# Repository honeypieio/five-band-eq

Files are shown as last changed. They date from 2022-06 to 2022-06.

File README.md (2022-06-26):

# Five-band EQ
Preamp and five-band EQ for guitar amplifiers

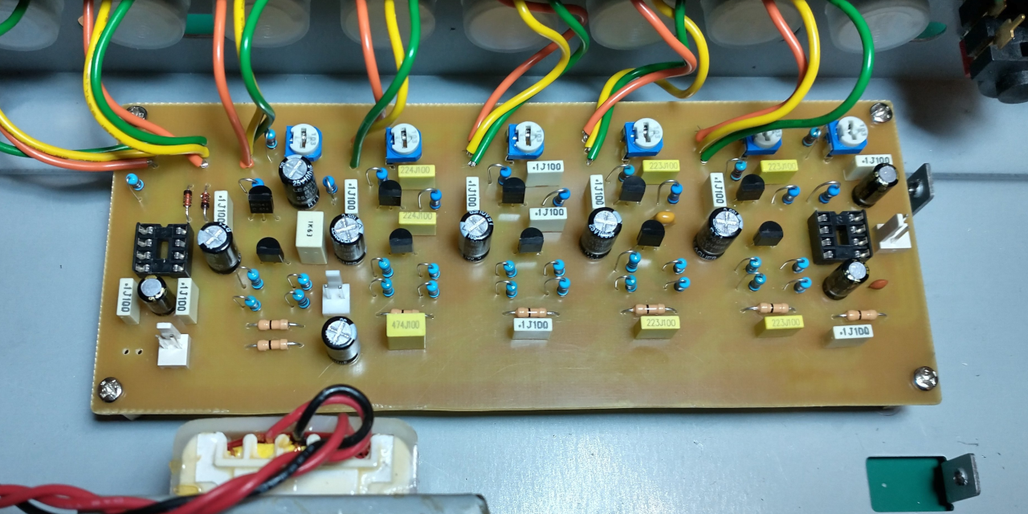
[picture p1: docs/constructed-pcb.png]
Photo of constructed PCB
 

The goal of this project is to create a simple guitar amplifier frontend using commonly available components

The PCB is single-sided and was created using Kicad. It is optimised for home etching - chunky traces, generous ground plane clearance

Key specifications:

* Requires a +/-15V power supply
* ~80mA quiescent current draw
* Adjustable input gain and attenuation
* Hard clipping diodes for distortion
* Five-band EQ - bass, middle, treble, presence, brilliance
* EQ 6dB boost/cut

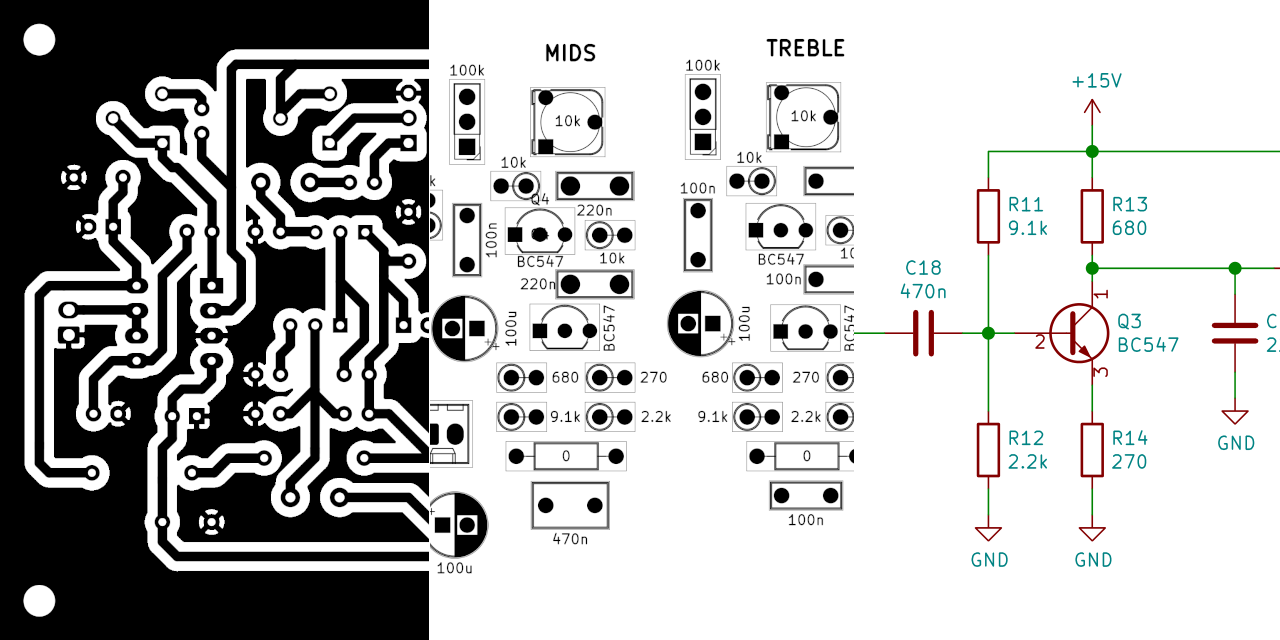
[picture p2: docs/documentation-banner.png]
Documentation banner
 

To build the project, everything needed is inside the `docs` directory

* PCB layout
* Bill of materials
* Silkscreen
* Schematics

An LTspice simulation is also available in the `simulation` directory

---

### To-do

* Add EQ alignment process instructions

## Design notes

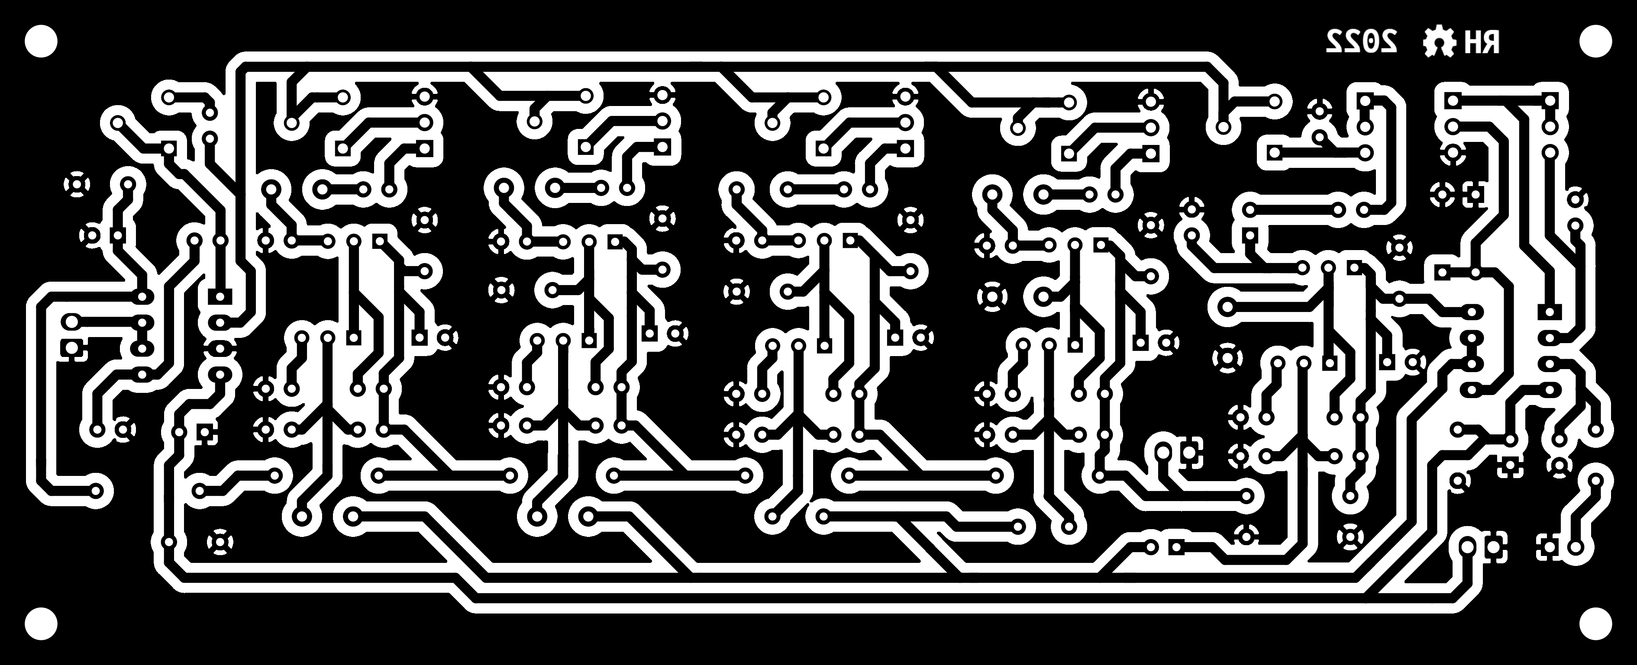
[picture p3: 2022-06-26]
docs/pcb-layout-copper-only.png

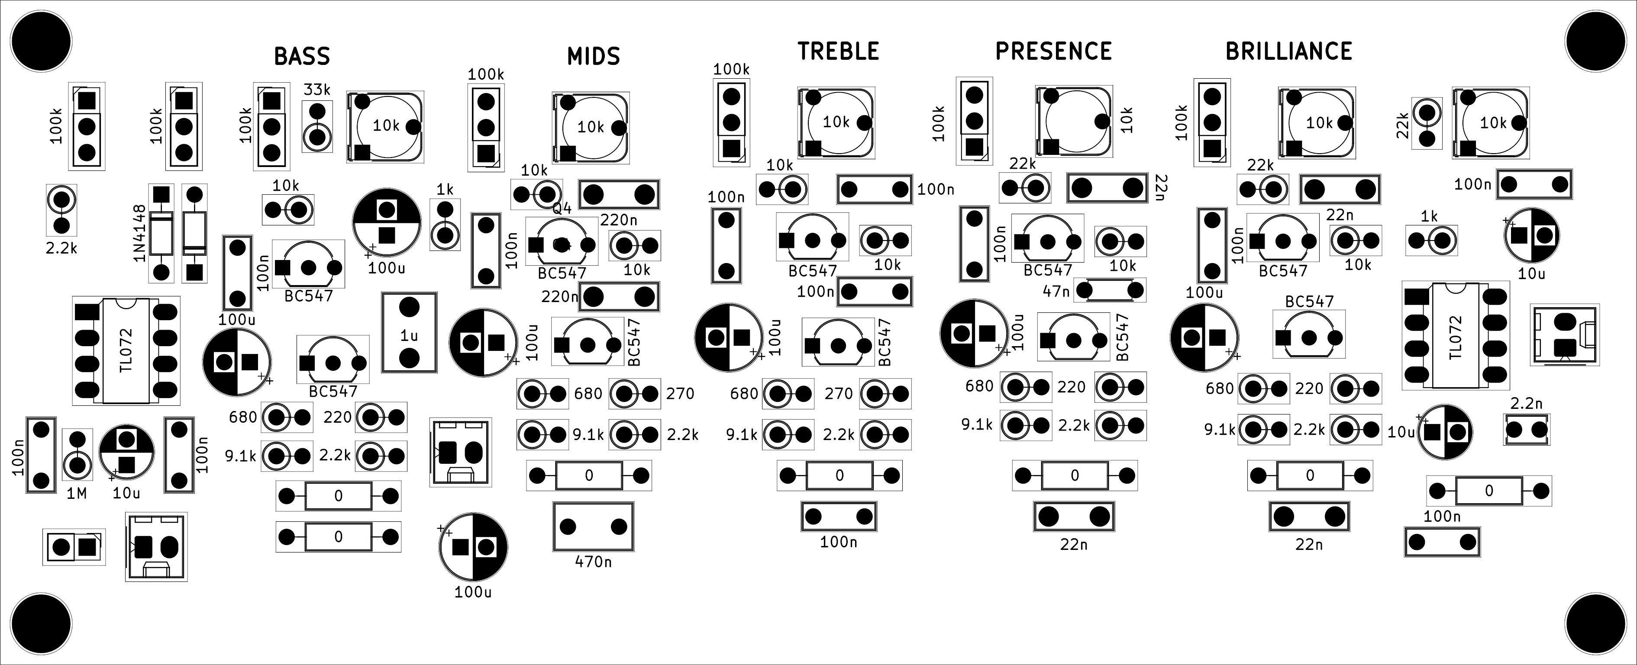
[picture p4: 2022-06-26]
docs/silkscreen.png

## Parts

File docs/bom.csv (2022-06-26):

Qty | Reference(s) | Value | LibPart | Footprint
12 | C1, C7, C9, C12, C16, C21, C23, C24, C25, C26, C31, C35 | 100n | Device:C | Capacitor_THT:C_Disc_D7.0mm_W2.5mm_P5.00mm
4 | C2, C6, C10, C11 | 10u | Device:CP1 | Capacitor_THT:CP_Radial_D5.0mm_P2.50mm
1 | C5 | 2.2n | Device:C | Capacitor_THT:C_Disc_D3.8mm_W2.6mm_P2.50mm
1 | C8 | 100n | Device:C_Small | Capacitor_THT:C_Disc_D7.0mm_W2.5mm_P5.00mm
7 | C13, C15, C17, C22, C27, C32, C36 | 100u | Device:CP1 | Capacitor_THT:CP_Radial_D6.3mm_P2.50mm
1 | C14 | 1u | Device:CP1 | Capacitor_THT:C_Disc_D7.5mm_W5.0mm_P5.00mm
1 | C18 | 470n | Device:C | Capacitor_THT:C_Disc_D7.5mm_W4.4mm_P5.00mm
2 | C19, C20 | 220n | Device:C | Capacitor_THT:C_Disc_D7.5mm_W2.5mm_P5.00mm
4 | C28, C30, C33, C34 | 22n | Device:C | Capacitor_THT:C_Disc_D7.5mm_W2.5mm_P5.00mm
1 | C29 | 47n | Device:C | Capacitor_THT:C_Disc_D4.3mm_W1.9mm_P5.00mm
2 | D1, D2 | 1N4148 | Diode:1N4148 | Diode_THT:D_DO-35_SOD27_P7.62mm_Horizontal
3 | J1, J2, J4 | Conn_01x02_Male | Connector:Conn_01x02_Male | Connector_Molex:Molex_KK-254_AE-6410-02A_1x02_P2.54mm_Vertical
1 | J3 | Conn_01x02_Male | Connector:Conn_01x02_Male | Connector_PinHeader_2.54mm:PinHeader_1x02_P2.54mm_Vertical
10 | Q1, Q2, Q3, Q4, Q5, Q6, Q7, Q8, Q9, Q10 | BC547 | Transistor_BJT:BC547 | Package_TO_SOT_THT:TO-92_Inline_Wide
3 | R1, R28, R34 | 22k | Device:R | Resistor_THT:R_Axial_DIN0207_L6.3mm_D2.5mm_P2.54mm_Vertical
2 | R2, R8 | 1k | Device:R | Resistor_THT:R_Axial_DIN0207_L6.3mm_D2.5mm_P2.54mm_Vertical
6 | R3, R5, R12, R18, R24, R30 | 2.2k | Device:R | Resistor_THT:R_Axial_DIN0207_L6.3mm_D2.5mm_P2.54mm_Vertical
5 | R4, R11, R17, R23, R29 | 9.1k | Device:R | Resistor_THT:R_Axial_DIN0207_L6.3mm_D2.5mm_P2.54mm_Vertical
5 | R6, R13, R19, R25, R31 | 680 | Device:R | Resistor_THT:R_Axial_DIN0207_L6.3mm_D2.5mm_P2.54mm_Vertical
3 | R7, R26, R32 | 220 | Device:R | Resistor_THT:R_Axial_DIN0207_L6.3mm_D2.5mm_P2.54mm_Vertical
7 | R9, R15, R16, R21, R22, R27, R33 | 10k | Device:R | Resistor_THT:R_Axial_DIN0207_L6.3mm_D2.5mm_P2.54mm_Vertical
1 | R10 | 33k | Device:R | Resistor_THT:R_Axial_DIN0207_L6.3mm_D2.5mm_P2.54mm_Vertical
2 | R14, R20 | 270 | Device:R | Resistor_THT:R_Axial_DIN0207_L6.3mm_D2.5mm_P2.54mm_Vertical
7 | R35, R36, R37, R38, R39, R40, R41 | 0 | Device:R | Resistor_THT:R_Axial_DIN0207_L6.3mm_D2.5mm_P10.16mm_Horizontal
1 | R42 | 1M | Device:R | Resistor_THT:R_Axial_DIN0207_L6.3mm_D2.5mm_P2.54mm_Vertical
6 | RV1, RV5, RV7, RV9, RV11, RV13 | 10k | Device:R_POT | Potentiometer_THT:Potentiometer_Runtron_RM-065_Vertical
2 | RV2, RV3 | 100k Logarithmic | Device:R_POT | Connector_PinHeader_2.54mm:PinHeader_1x03_P2.54mm_Vertical
5 | RV4, RV6, RV8, RV10, RV12 | 100k Linear | Device:R_POT | Connector_PinHeader_2.54mm:PinHeader_1x03_P2.54mm_Vertical
2 | U1, U2 | TL072 | Amplifier_Operational:TL072 | Package_DIP:DIP-8_W7.62mm_LongPads

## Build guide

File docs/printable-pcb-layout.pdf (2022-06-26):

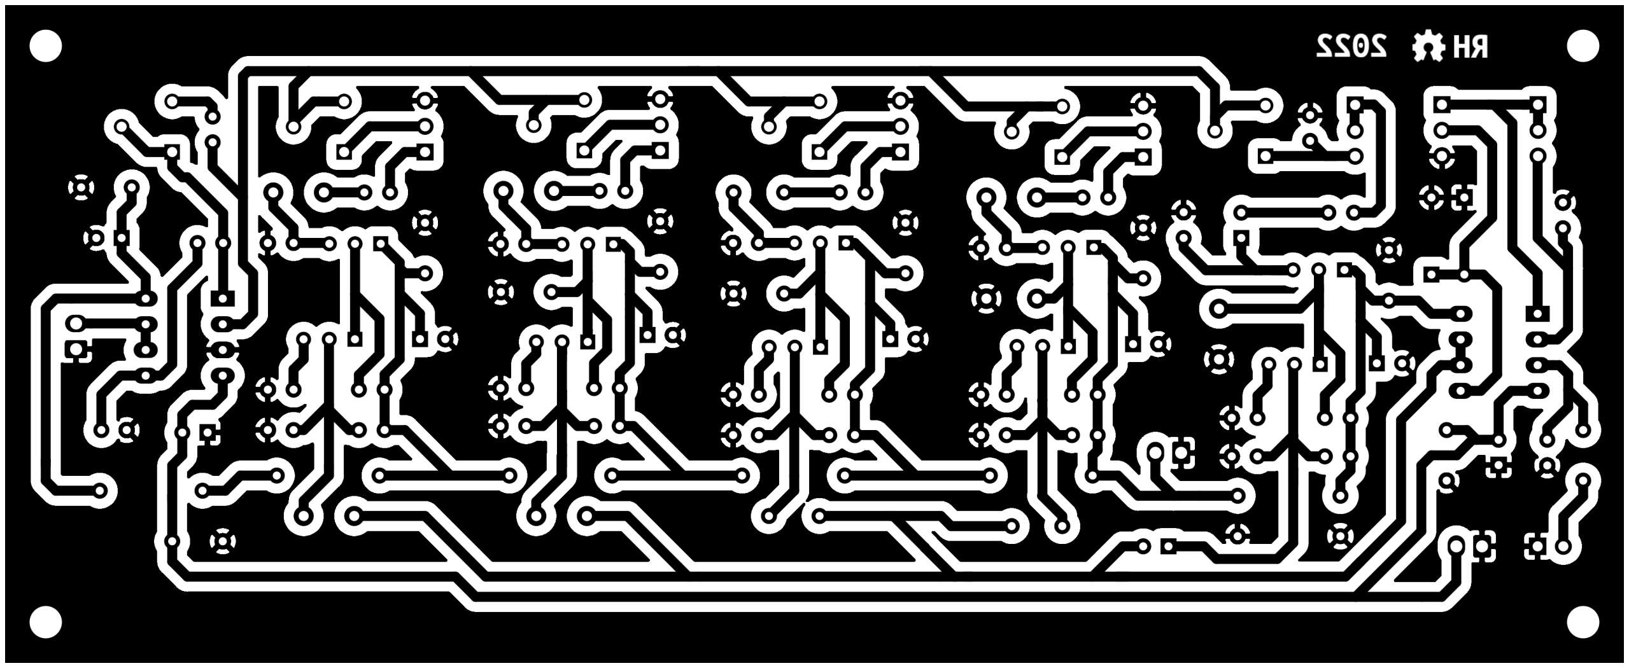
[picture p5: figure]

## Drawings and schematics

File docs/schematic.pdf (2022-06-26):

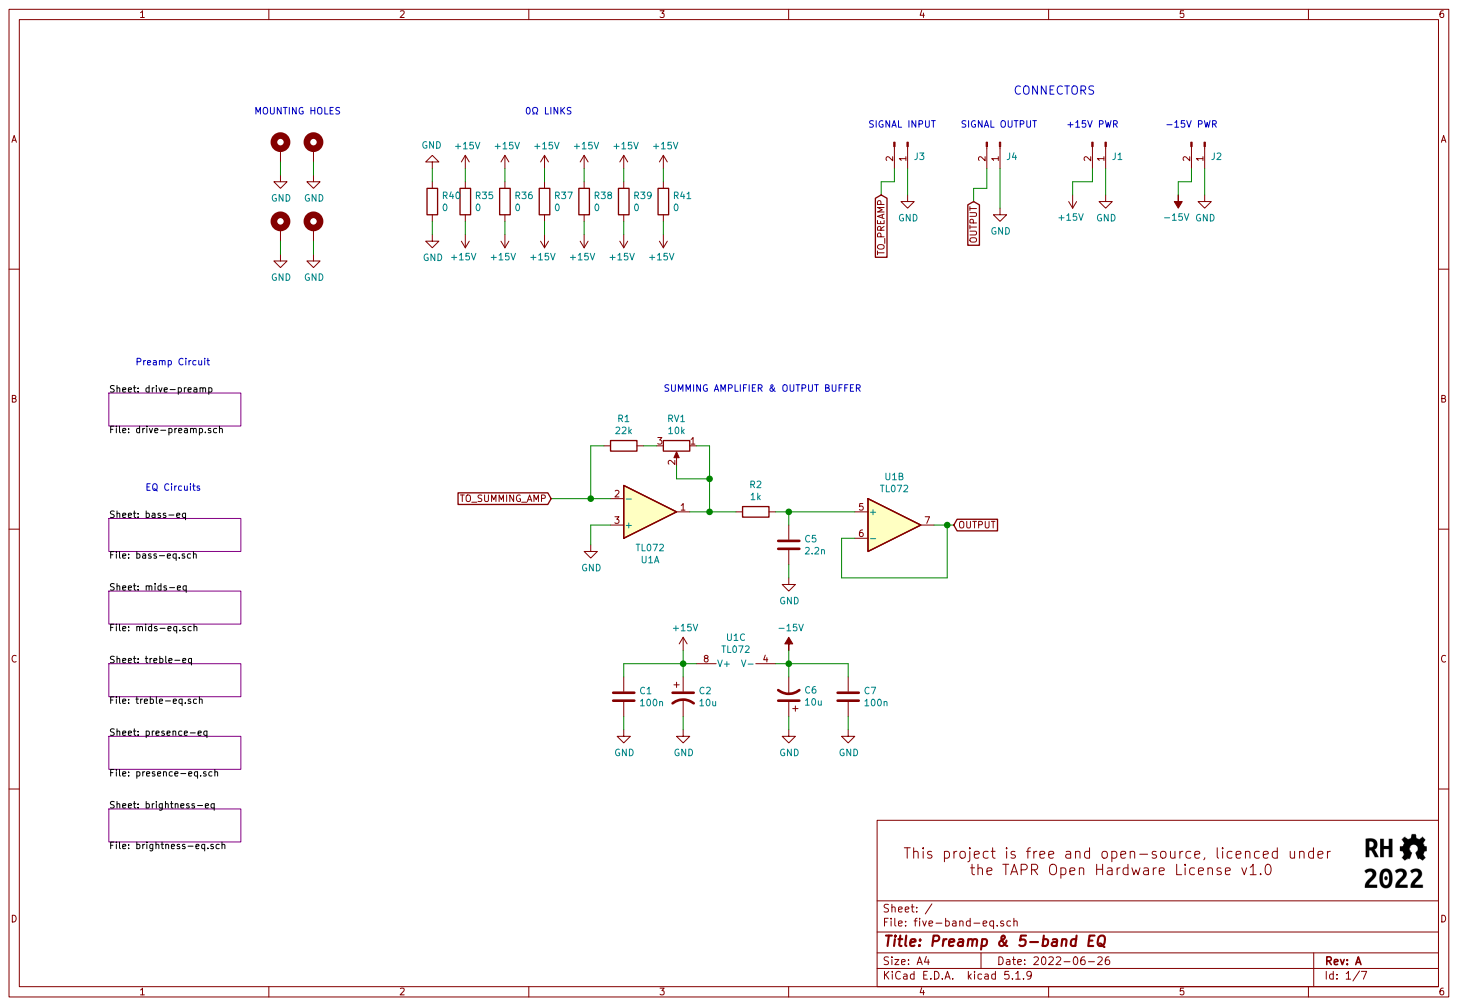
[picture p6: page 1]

0 GND GND GND GND

File: bass-eq.sch

File: mids-eq.sch

File: treble-eq.sch

File: presence-eq.sch

File: brightness-eq.sch

File: five-band-eq.sch Sheet: / This project is free and open-source, licenced under

the TAPR Open Hardware License v1.0

Id: 1/7 Title: Preamp & 5-band EQ

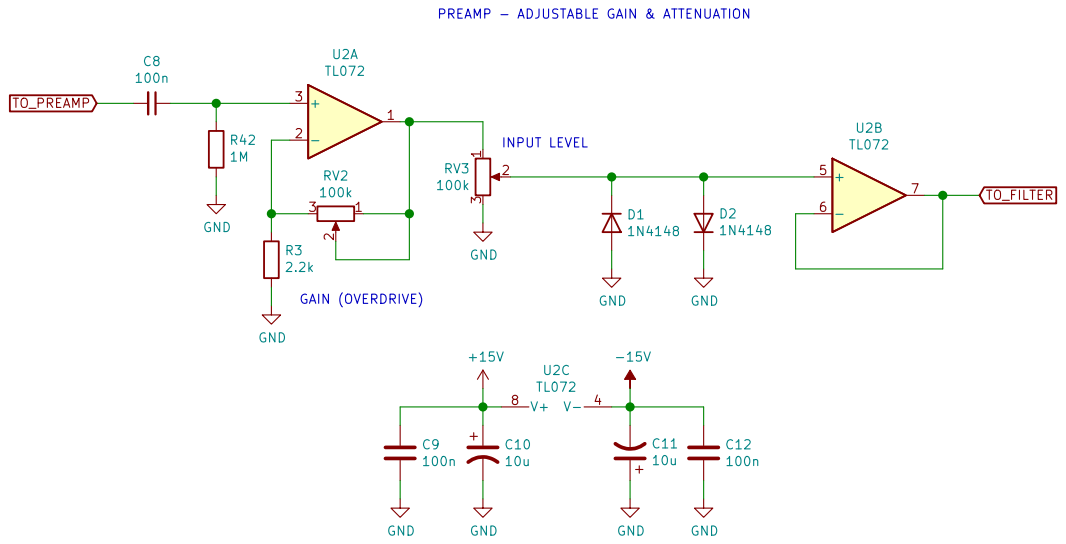
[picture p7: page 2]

PREAMP - ADJUSTABLE GAIN & ATTENUATION

INPUT LEVEL GAIN (OVERDRIVE)

This project is free and open-source, licenced under

the TAPR Open Hardware License v1.0

Sheet: /drive-preamp/
File: drive-preamp.sch
Id: 2/7 Title: Preamp & 5-band EQ

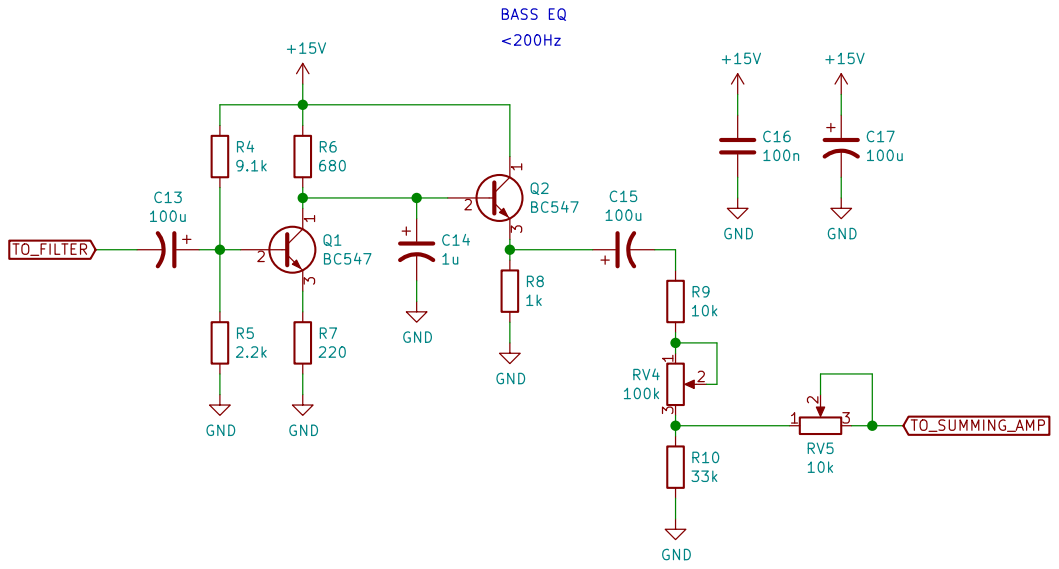
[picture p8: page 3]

This project is free and open-source, licenced under

the TAPR Open Hardware License v1.0

Sheet: /bass-eq/
File: bass-eq.sch
Id: 3/7 Title: Preamp & 5-band EQ

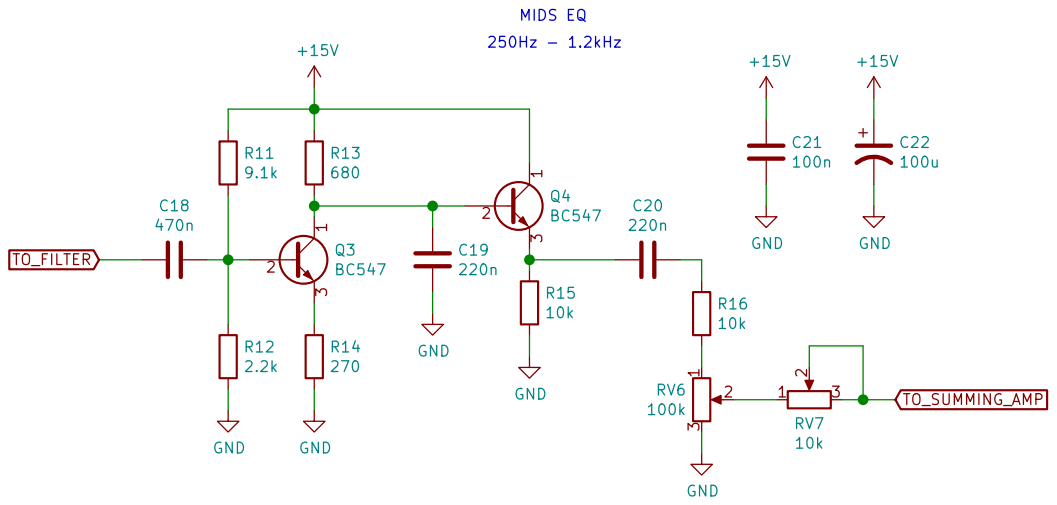
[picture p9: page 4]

This project is free and open-source, licenced under

the TAPR Open Hardware License v1.0

Sheet: /mids-eq/
File: mids-eq.sch
Id: 4/7 Title: Preamp & 5-band EQ

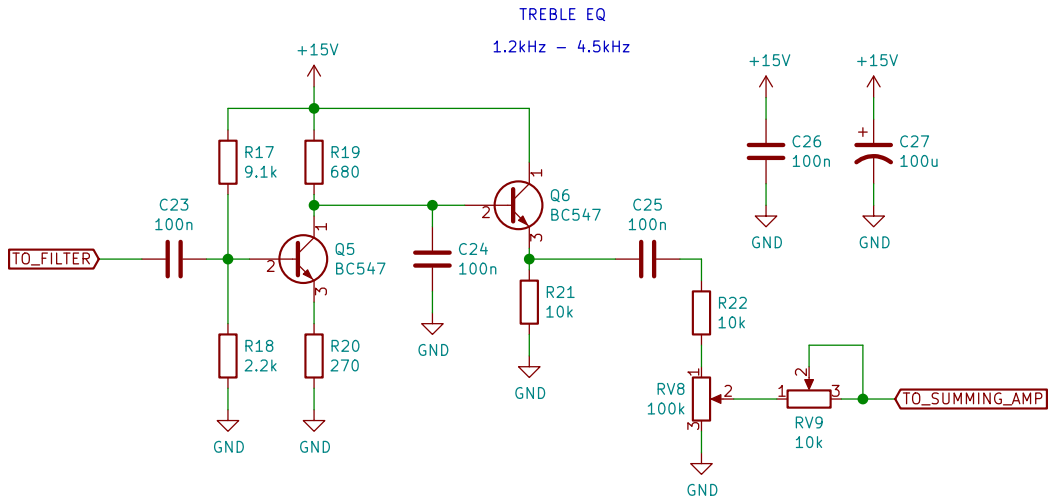
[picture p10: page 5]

This project is free and open-source, licenced under

the TAPR Open Hardware License v1.0

Sheet: /treble-eq/
File: treble-eq.sch
Id: 5/7 Title: Preamp & 5-band EQ

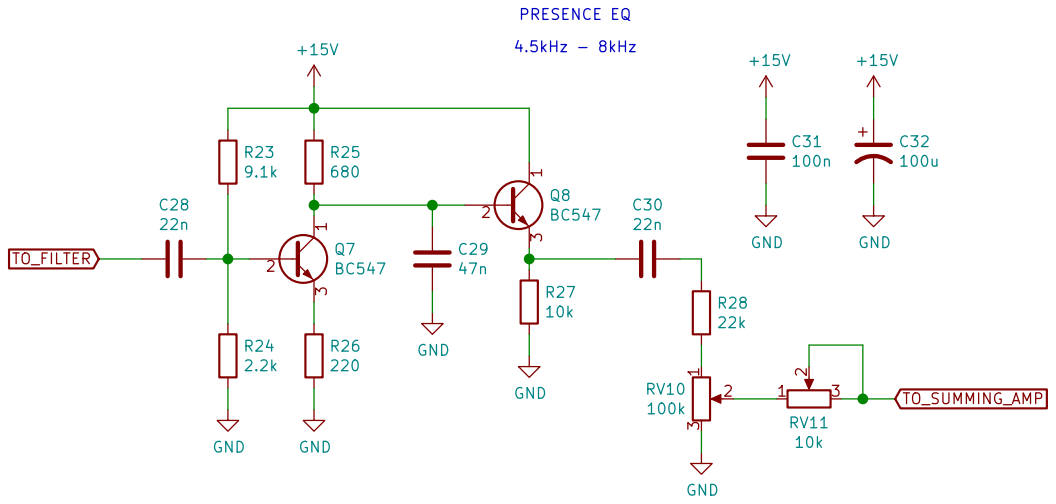
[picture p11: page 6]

This project is free and open-source, licenced under

the TAPR Open Hardware License v1.0

Sheet: /presence-eq/
File: presence-eq.sch
Id: 6/7 Title: Preamp & 5-band EQ

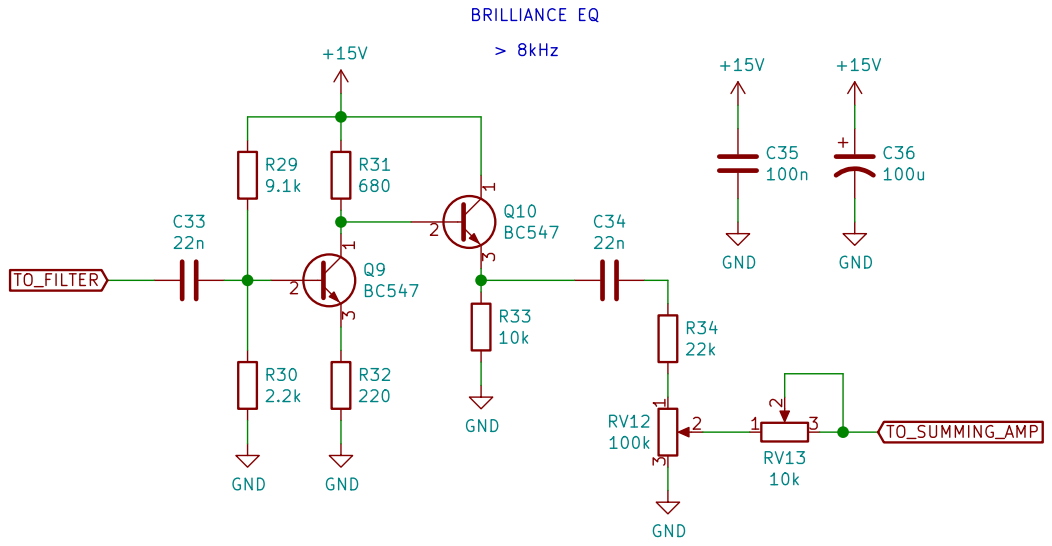
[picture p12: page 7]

This project is free and open-source, licenced under

the TAPR Open Hardware License v1.0

Sheet: /brightness-eq/
File: brightness-eq.sch
Id: 7/7 Title: Preamp & 5-band EQ

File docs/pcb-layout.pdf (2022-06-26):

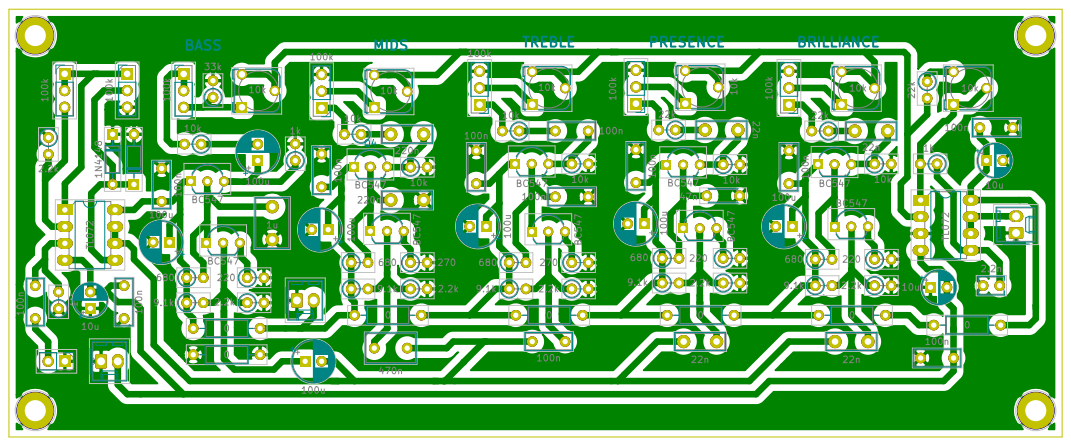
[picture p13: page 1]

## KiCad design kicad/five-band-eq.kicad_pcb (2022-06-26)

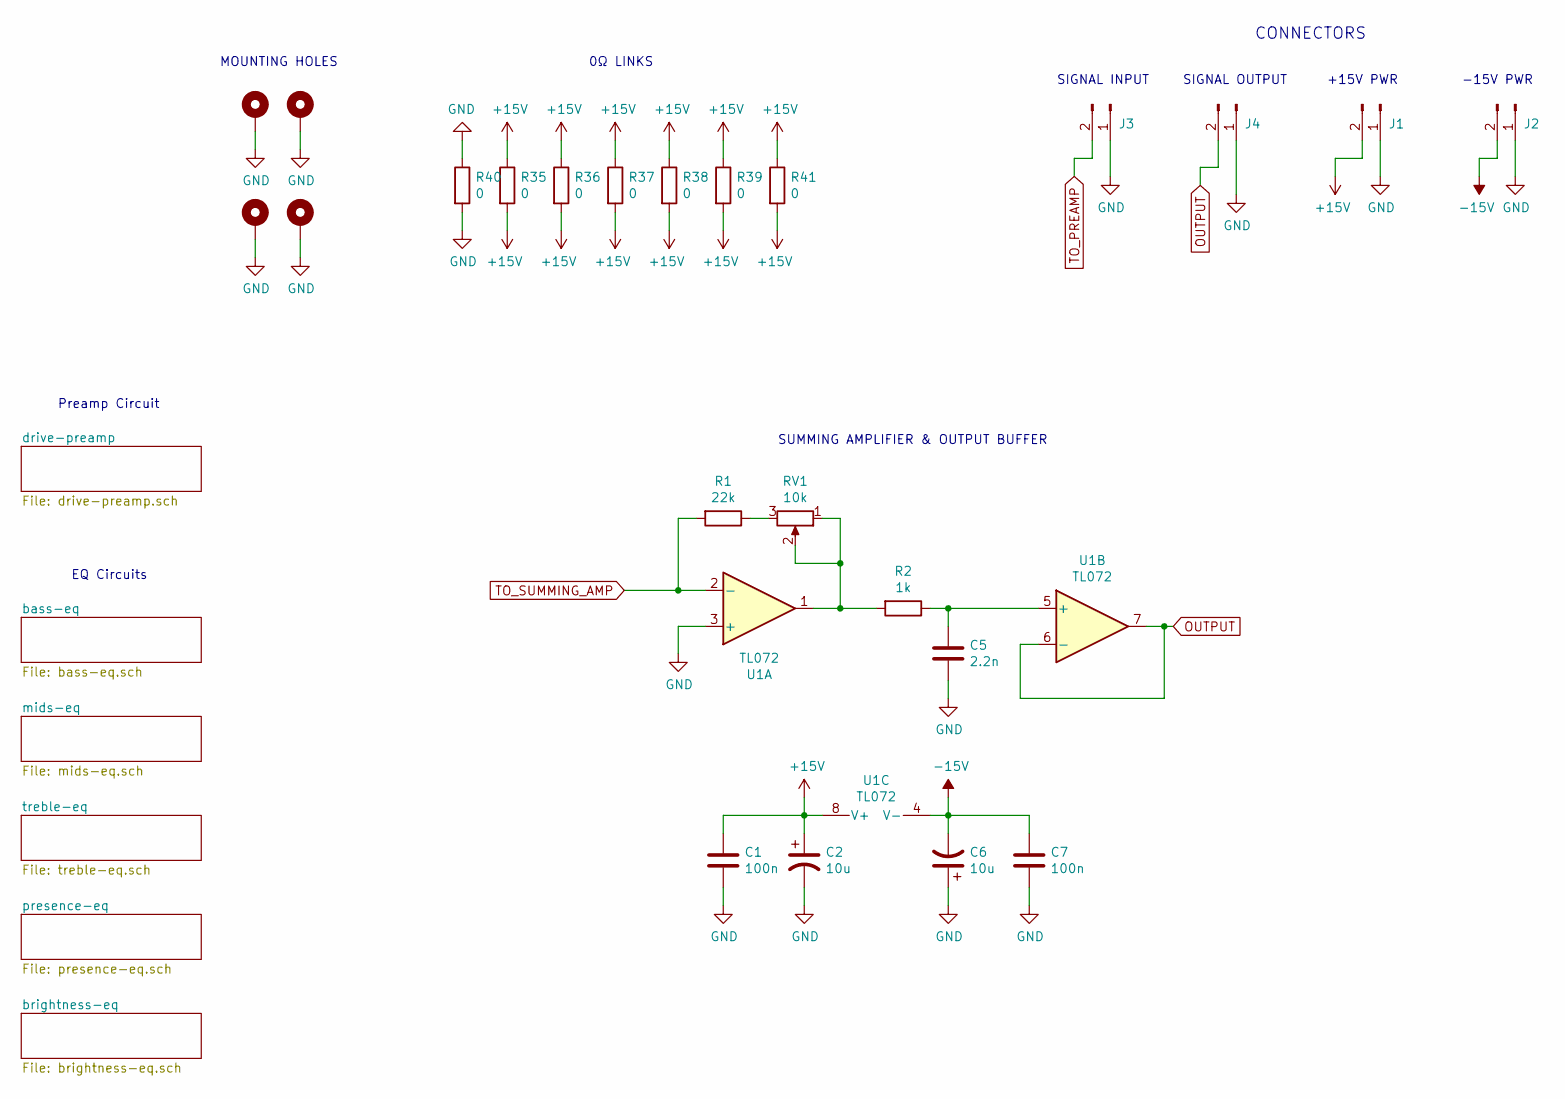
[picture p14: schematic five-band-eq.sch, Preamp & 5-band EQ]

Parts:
C1, C7: 100n; C_Disc_D7.0mm_W2.5mm_P5.00mm
C2, C6: 10u; CP_Radial_D5.0mm_P2.50mm
C5: 2.2n; C_Disc_D3.8mm_W2.6mm_P2.50mm
H1, H2, H3, H4: MountingHole_Pad; MountingHole_3.2mm_M3_DIN965_Pad
J1, J2, J4: Conn_01x02_Male; Molex_KK-254_AE-6410-02A_1x02_P2.54mm_Vertical
J3: Conn_01x02_Male; PinHeader_1x02_P2.54mm_Vertical
R1: 22k; R_Axial_DIN0207_L6.3mm_D2.5mm_P2.54mm_Vertical
R2: 1k; R_Axial_DIN0207_L6.3mm_D2.5mm_P2.54mm_Vertical
R35, R36, R37, R38, R39, R40, R41: 0; R_Axial_DIN0207_L6.3mm_D2.5mm_P10.16mm_Horizontal
RV1: 10k; Potentiometer_Runtron_RM-065_Vertical
U1: TL072; DIP-8_W7.62mm_LongPads

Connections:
+15V: C1.1, C2.1, J1.2, R35.1, R35.2, R36.1, R36.2, R37.1, R37.2, R38.1, R38.2, R39.1, R39.2, R41.1, R41.2, U1.8 (V+); also elsewhere on the board
-15V: C6.2, C7.1, J2.2, U1.4 (V-); also elsewhere on the board
GND: C1.2, C2.2, C5.2, C6.1, C7.2, H1.1, H2.1, H3.1, H4.1, J1.1, J2.1, J3.1, J4.1, R40.1, R40.2, U1.3 (+); also elsewhere on the board
unnamed: C5.1, R2.1, U1.5 (+)
unnamed: R1.1, RV1.3
unnamed: R2.2, RV1.1, RV1.2, U1.1
OUTPUT: J4.2, U1.6 (-), U1.7
TO_PREAMP: J3.2; also elsewhere on the board
TO_SUMMING_AMP: R1.2, U1.2 (-); also elsewhere on the board

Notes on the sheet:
0Ω LINKS
MOUNTING HOLES
SIGNAL INPUT
SIGNAL OUTPUT
+15V PWR
-15V PWR
CONNECTORS
SUMMING AMPLIFIER & OUTPUT BUFFER
EQ Circuits
Preamp Circuit

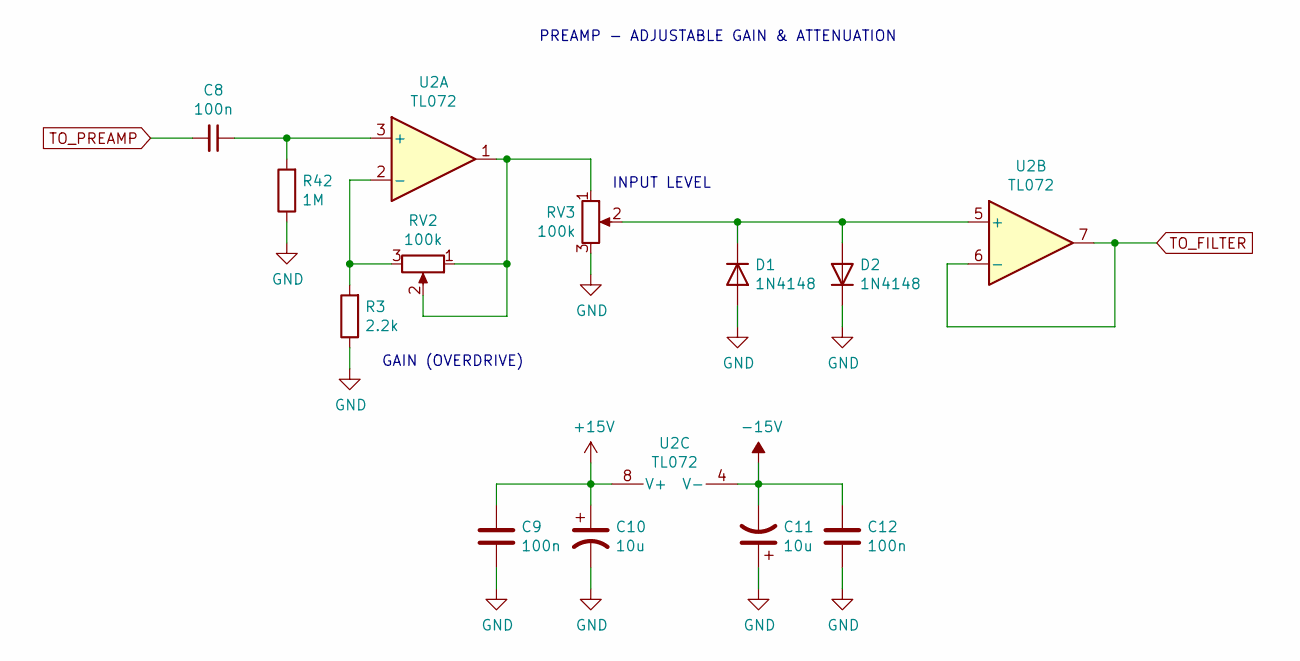
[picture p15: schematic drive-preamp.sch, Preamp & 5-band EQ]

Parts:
C8, C9, C12: 100n; C_Disc_D7.0mm_W2.5mm_P5.00mm
C10, C11: 10u; CP_Radial_D5.0mm_P2.50mm
D1, D2: 1N4148; D_DO-35_SOD27_P7.62mm_Horizontal
R3: 2.2k; R_Axial_DIN0207_L6.3mm_D2.5mm_P2.54mm_Vertical
R42: 1M; R_Axial_DIN0207_L6.3mm_D2.5mm_P2.54mm_Vertical
RV2, RV3: 100k; PinHeader_1x03_P2.54mm_Vertical
U2: TL072; DIP-8_W7.62mm_LongPads

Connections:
+15V: C9.1, C10.1, U2.8 (V+); also elsewhere on the board
-15V: C11.2, C12.1, U2.4 (V-); also elsewhere on the board
GND: C9.2, C10.2, C11.1, C12.2, D1.2 (A), D2.1 (K), R3.1, R42.1, RV3.3; also elsewhere on the board
unnamed: C8.1, R42.2, U2.3 (+)
unnamed: D1.1 (K), D2.2 (A), RV3.2, U2.5 (+)
unnamed: R3.2, RV2.3, U2.2 (-)
unnamed: RV2.1, RV2.2, RV3.1, U2.1
TO_FILTER: U2.6 (-), U2.7; also elsewhere on the board
TO_PREAMP: C8.2; also elsewhere on the board

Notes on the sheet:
GAIN (OVERDRIVE)
INPUT LEVEL
PREAMP - ADJUSTABLE GAIN & ATTENUATION

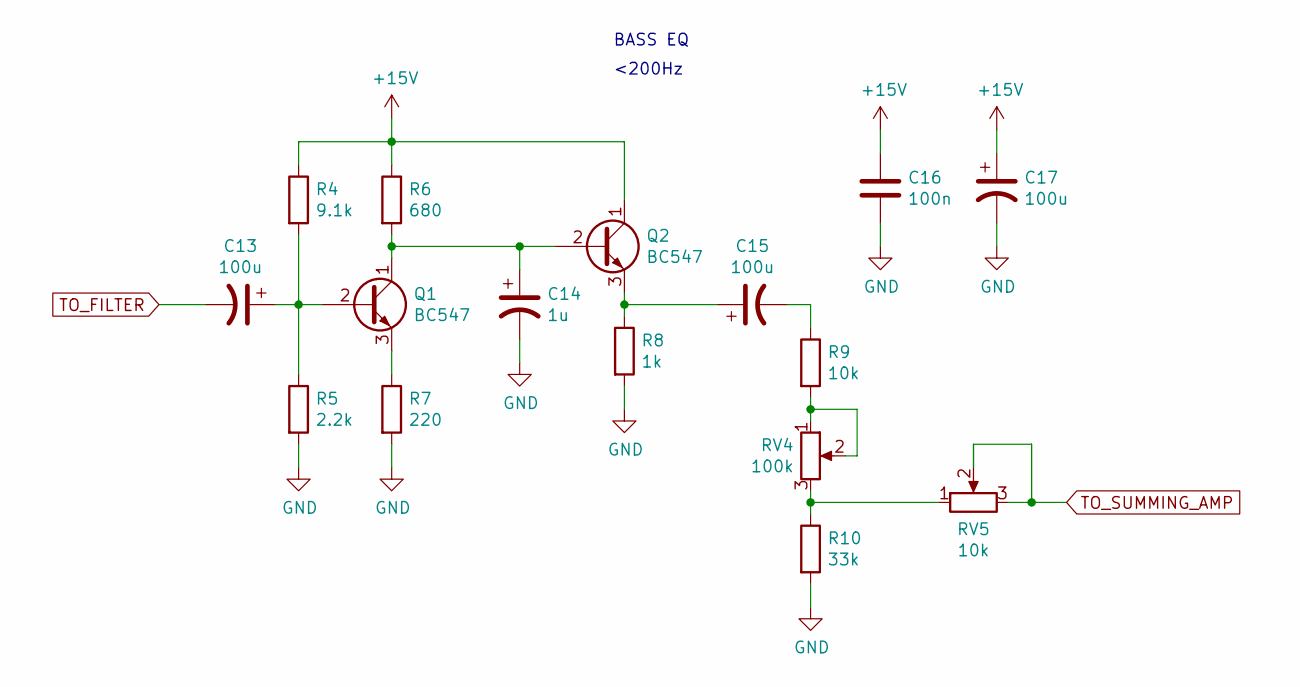
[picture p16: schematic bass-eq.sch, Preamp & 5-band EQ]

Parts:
C13, C15, C17: 100u; CP_Radial_D6.3mm_P2.50mm
C14: 1u; C_Disc_D7.5mm_W5.0mm_P5.00mm
C16: 100n; C_Disc_D7.0mm_W2.5mm_P5.00mm
Q1, Q2: BC547; TO-92_Inline_Wide
R4: 9.1k; R_Axial_DIN0207_L6.3mm_D2.5mm_P2.54mm_Vertical
R5: 2.2k; R_Axial_DIN0207_L6.3mm_D2.5mm_P2.54mm_Vertical
R6: 680; R_Axial_DIN0207_L6.3mm_D2.5mm_P2.54mm_Vertical
R7: 220; R_Axial_DIN0207_L6.3mm_D2.5mm_P2.54mm_Vertical
R8: 1k; R_Axial_DIN0207_L6.3mm_D2.5mm_P2.54mm_Vertical
R9: 10k; R_Axial_DIN0207_L6.3mm_D2.5mm_P2.54mm_Vertical
R10: 33k; R_Axial_DIN0207_L6.3mm_D2.5mm_P2.54mm_Vertical
RV4: 100k; PinHeader_1x03_P2.54mm_Vertical
RV5: 10k; Potentiometer_Runtron_RM-065_Vertical

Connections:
+15V: C16.1, C17.1, Q2.1 (C), R4.1, R6.1; also elsewhere on the board
GND: C14.2, C16.2, C17.2, R5.2, R7.2, R8.2, R10.2; also elsewhere on the board
unnamed: C13.1, Q1.2 (B), R4.2, R5.1
unnamed: C14.1, Q1.1 (C), Q2.2 (B), R6.2
unnamed: C15.1, Q2.3 (E), R8.1
unnamed: C15.2, R9.1
unnamed: Q1.3 (E), R7.1
unnamed: R9.2, RV4.1, RV4.2
unnamed: R10.1, RV4.3, RV5.1
TO_FILTER: C13.2; also elsewhere on the board
TO_SUMMING_AMP: RV5.2, RV5.3; also elsewhere on the board

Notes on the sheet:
BASS EQ
<200Hz

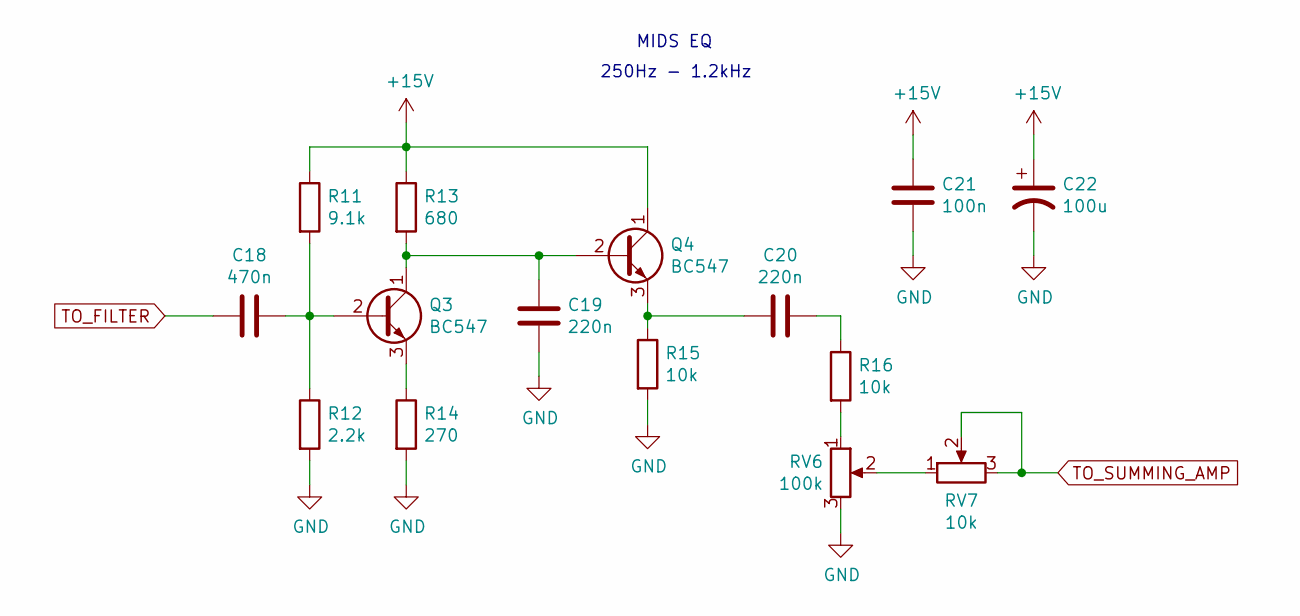
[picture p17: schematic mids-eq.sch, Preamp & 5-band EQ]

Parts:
C18: 470n; C_Disc_D7.5mm_W4.4mm_P5.00mm
C19, C20: 220n; C_Disc_D7.5mm_W2.5mm_P5.00mm
C21: 100n; C_Disc_D7.0mm_W2.5mm_P5.00mm
C22: 100u; CP_Radial_D6.3mm_P2.50mm
Q3, Q4: BC547; TO-92_Inline_Wide
R11: 9.1k; R_Axial_DIN0207_L6.3mm_D2.5mm_P2.54mm_Vertical
R12: 2.2k; R_Axial_DIN0207_L6.3mm_D2.5mm_P2.54mm_Vertical
R13: 680; R_Axial_DIN0207_L6.3mm_D2.5mm_P2.54mm_Vertical
R14: 270; R_Axial_DIN0207_L6.3mm_D2.5mm_P2.54mm_Vertical
R15, R16: 10k; R_Axial_DIN0207_L6.3mm_D2.5mm_P2.54mm_Vertical
RV6: 100k; PinHeader_1x03_P2.54mm_Vertical
RV7: 10k; Potentiometer_Runtron_RM-065_Vertical

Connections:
+15V: C21.1, C22.1, Q4.1 (C), R11.1, R13.1; also elsewhere on the board
GND: C19.2, C21.2, C22.2, R12.2, R14.2, R15.2, RV6.3; also elsewhere on the board
unnamed: C18.1, Q3.2 (B), R11.2, R12.1
unnamed: C19.1, Q3.1 (C), Q4.2 (B), R13.2
unnamed: C20.1, R16.1
unnamed: C20.2, Q4.3 (E), R15.1
unnamed: Q3.3 (E), R14.1
unnamed: R16.2, RV6.1
unnamed: RV6.2, RV7.1
TO_FILTER: C18.2; also elsewhere on the board
TO_SUMMING_AMP: RV7.2, RV7.3; also elsewhere on the board

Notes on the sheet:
MIDS EQ
250Hz - 1.2kHz

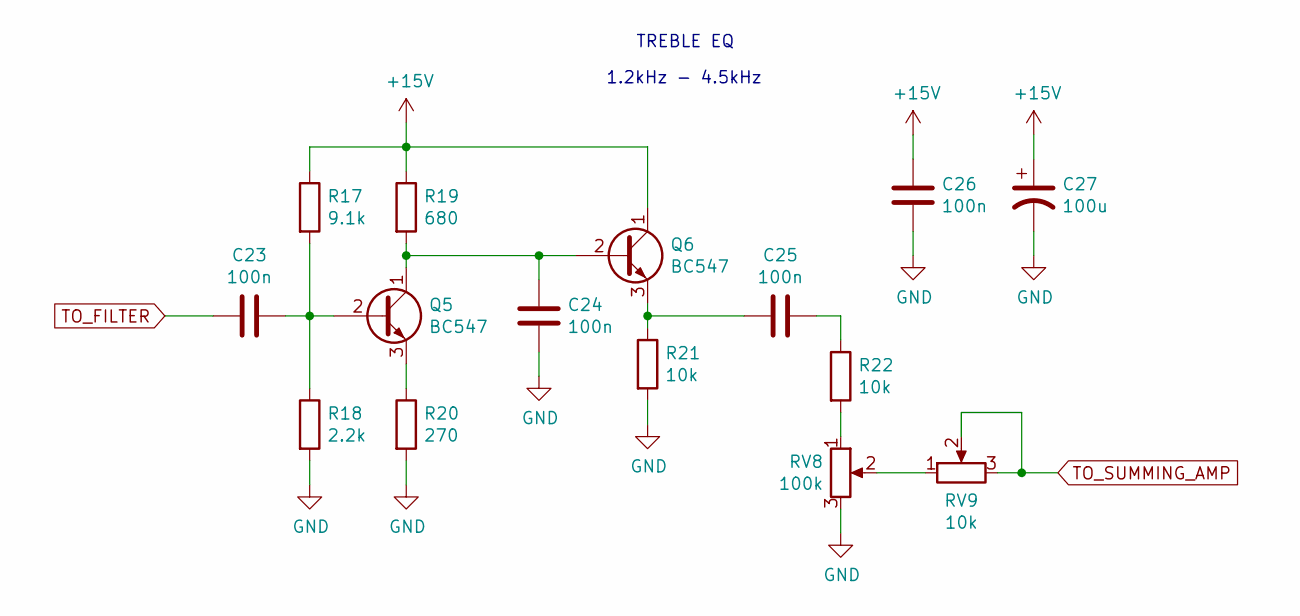
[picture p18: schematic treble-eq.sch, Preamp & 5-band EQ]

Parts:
C23, C24, C25, C26: 100n; C_Disc_D7.0mm_W2.5mm_P5.00mm
C27: 100u; CP_Radial_D6.3mm_P2.50mm
Q5, Q6: BC547; TO-92_Inline_Wide
R17: 9.1k; R_Axial_DIN0207_L6.3mm_D2.5mm_P2.54mm_Vertical
R18: 2.2k; R_Axial_DIN0207_L6.3mm_D2.5mm_P2.54mm_Vertical
R19: 680; R_Axial_DIN0207_L6.3mm_D2.5mm_P2.54mm_Vertical
R20: 270; R_Axial_DIN0207_L6.3mm_D2.5mm_P2.54mm_Vertical
R21, R22: 10k; R_Axial_DIN0207_L6.3mm_D2.5mm_P2.54mm_Vertical
RV8: 100k; PinHeader_1x03_P2.54mm_Vertical
RV9: 10k; Potentiometer_Runtron_RM-065_Vertical

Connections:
+15V: C26.1, C27.1, Q6.1 (C), R17.1, R19.1; also elsewhere on the board
GND: C24.2, C26.2, C27.2, R18.2, R20.2, R21.2, RV8.3; also elsewhere on the board
unnamed: C23.1, Q5.2 (B), R17.2, R18.1
unnamed: C24.1, Q5.1 (C), Q6.2 (B), R19.2
unnamed: C25.1, R22.1
unnamed: C25.2, Q6.3 (E), R21.1
unnamed: Q5.3 (E), R20.1
unnamed: R22.2, RV8.1
unnamed: RV8.2, RV9.1
TO_FILTER: C23.2; also elsewhere on the board
TO_SUMMING_AMP: RV9.2, RV9.3; also elsewhere on the board

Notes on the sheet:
TREBLE EQ
1.2kHz - 4.5kHz

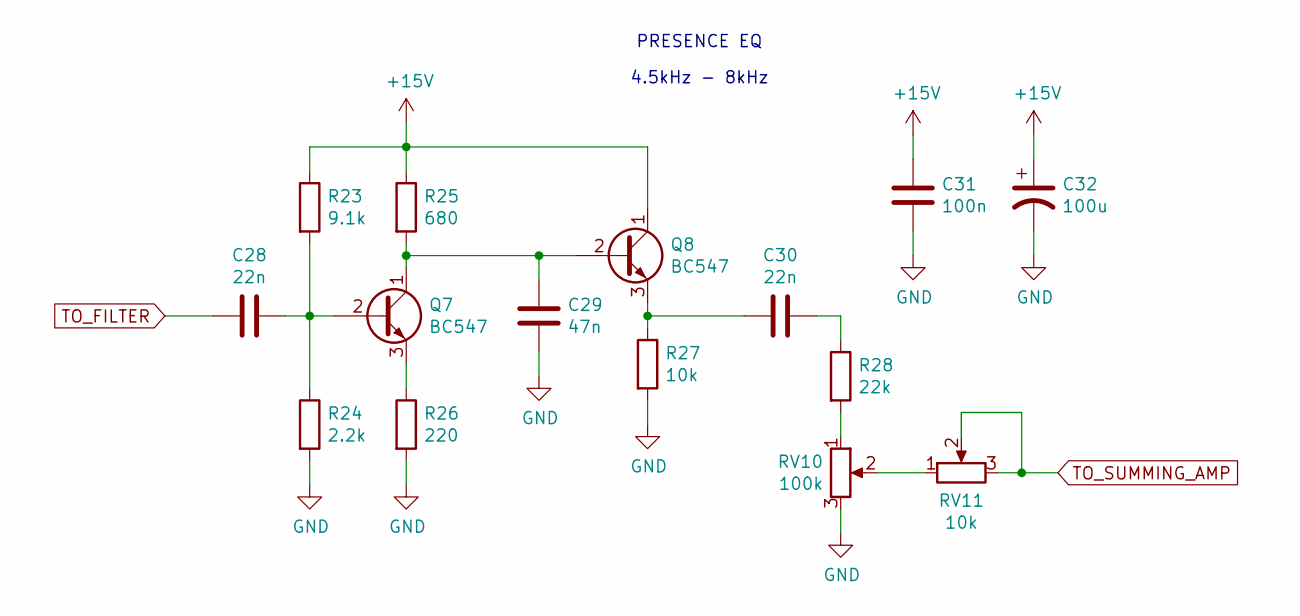
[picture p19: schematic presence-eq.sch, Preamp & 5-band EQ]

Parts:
C28, C30: 22n; C_Disc_D7.5mm_W2.5mm_P5.00mm
C29: 47n; C_Disc_D4.3mm_W1.9mm_P5.00mm
C31: 100n; C_Disc_D7.0mm_W2.5mm_P5.00mm
C32: 100u; CP_Radial_D6.3mm_P2.50mm
Q7, Q8: BC547; TO-92_Inline_Wide
R23: 9.1k; R_Axial_DIN0207_L6.3mm_D2.5mm_P2.54mm_Vertical
R24: 2.2k; R_Axial_DIN0207_L6.3mm_D2.5mm_P2.54mm_Vertical
R25: 680; R_Axial_DIN0207_L6.3mm_D2.5mm_P2.54mm_Vertical
R26: 220; R_Axial_DIN0207_L6.3mm_D2.5mm_P2.54mm_Vertical
R27: 10k; R_Axial_DIN0207_L6.3mm_D2.5mm_P2.54mm_Vertical
R28: 22k; R_Axial_DIN0207_L6.3mm_D2.5mm_P2.54mm_Vertical
RV10: 100k; PinHeader_1x03_P2.54mm_Vertical
RV11: 10k; Potentiometer_Runtron_RM-065_Vertical

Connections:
+15V: C31.1, C32.1, Q8.1 (C), R23.1, R25.1; also elsewhere on the board
GND: C29.2, C31.2, C32.2, R24.2, R26.2, R27.2, RV10.3; also elsewhere on the board
unnamed: C28.1, Q7.2 (B), R23.2, R24.1
unnamed: C29.1, Q7.1 (C), Q8.2 (B), R25.2
unnamed: C30.1, R28.1
unnamed: C30.2, Q8.3 (E), R27.1
unnamed: Q7.3 (E), R26.1
unnamed: R28.2, RV10.1
unnamed: RV10.2, RV11.1
TO_FILTER: C28.2; also elsewhere on the board
TO_SUMMING_AMP: RV11.2, RV11.3; also elsewhere on the board

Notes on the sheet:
PRESENCE EQ
4.5kHz - 8kHz

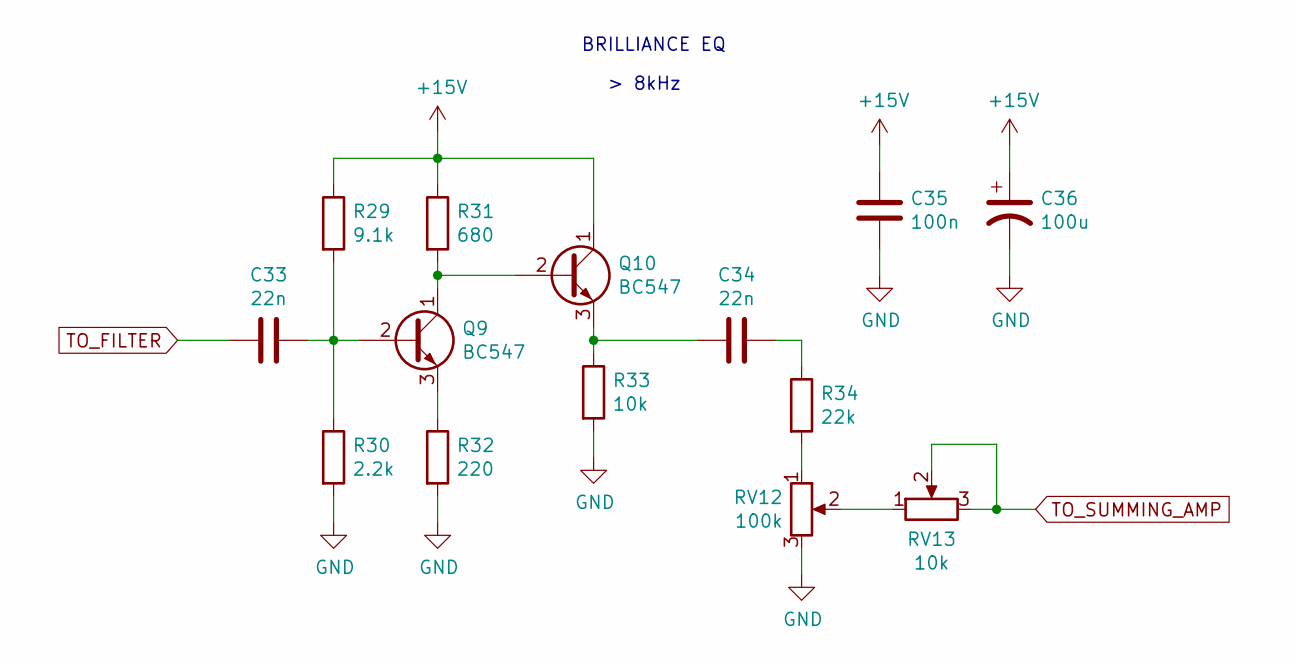
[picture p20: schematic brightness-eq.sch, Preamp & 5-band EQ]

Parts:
C33, C34: 22n; C_Disc_D7.5mm_W2.5mm_P5.00mm
C35: 100n; C_Disc_D7.0mm_W2.5mm_P5.00mm
C36: 100u; CP_Radial_D6.3mm_P2.50mm
Q9, Q10: BC547; TO-92_Inline_Wide
R29: 9.1k; R_Axial_DIN0207_L6.3mm_D2.5mm_P2.54mm_Vertical
R30: 2.2k; R_Axial_DIN0207_L6.3mm_D2.5mm_P2.54mm_Vertical
R31: 680; R_Axial_DIN0207_L6.3mm_D2.5mm_P2.54mm_Vertical
R32: 220; R_Axial_DIN0207_L6.3mm_D2.5mm_P2.54mm_Vertical
R33: 10k; R_Axial_DIN0207_L6.3mm_D2.5mm_P2.54mm_Vertical
R34: 22k; R_Axial_DIN0207_L6.3mm_D2.5mm_P2.54mm_Vertical
RV12: 100k; PinHeader_1x03_P2.54mm_Vertical
RV13: 10k; Potentiometer_Runtron_RM-065_Vertical

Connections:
+15V: C35.1, C36.1, Q10.1 (C), R29.1, R31.1; also elsewhere on the board
GND: C35.2, C36.2, R30.2, R32.2, R33.2, RV12.3; also elsewhere on the board
unnamed: C33.1, Q9.2 (B), R29.2, R30.1
unnamed: C34.1, R34.1
unnamed: C34.2, Q10.3 (E), R33.1
unnamed: Q9.3 (E), R32.1
unnamed: Q9.1 (C), Q10.2 (B), R31.2
unnamed: R34.2, RV12.1
unnamed: RV12.2, RV13.1
TO_FILTER: C33.2; also elsewhere on the board
TO_SUMMING_AMP: RV13.2, RV13.3; also elsewhere on the board

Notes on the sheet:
BRILLIANCE EQ
> 8kHz

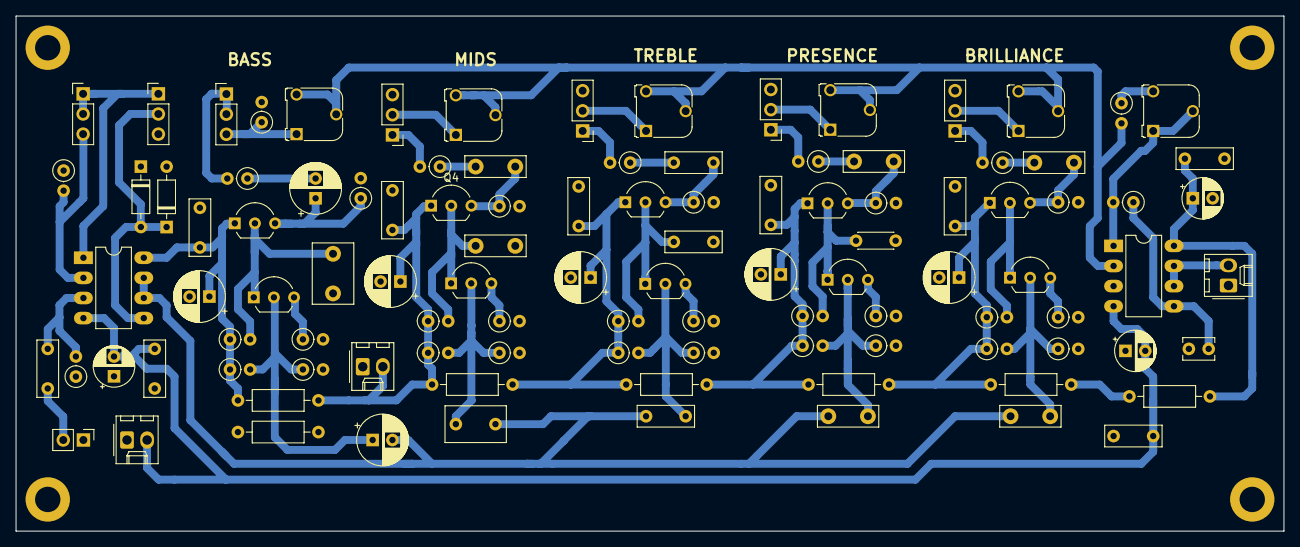
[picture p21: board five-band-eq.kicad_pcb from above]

Board: 2 copper layers, 160.0 x 65.0 mm, 109 parts (0 on the bottom side), 49 nets.

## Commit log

2022-06-26 Revision A
    [bass-eq.sch, bom.csv, brightness-eq.sch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]
2022-06-26 Added image of constructed PCB
